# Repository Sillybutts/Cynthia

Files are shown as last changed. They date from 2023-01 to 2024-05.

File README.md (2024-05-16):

# Cynthia
Cynthia is a Talon mag fed bolt action blaster, customizable for any need. 

<details>
<summary>Changelog (click this text, it's a dropdown!)</summary>

- Changelog: 3-31-2023: Blaster release.
  
</details>

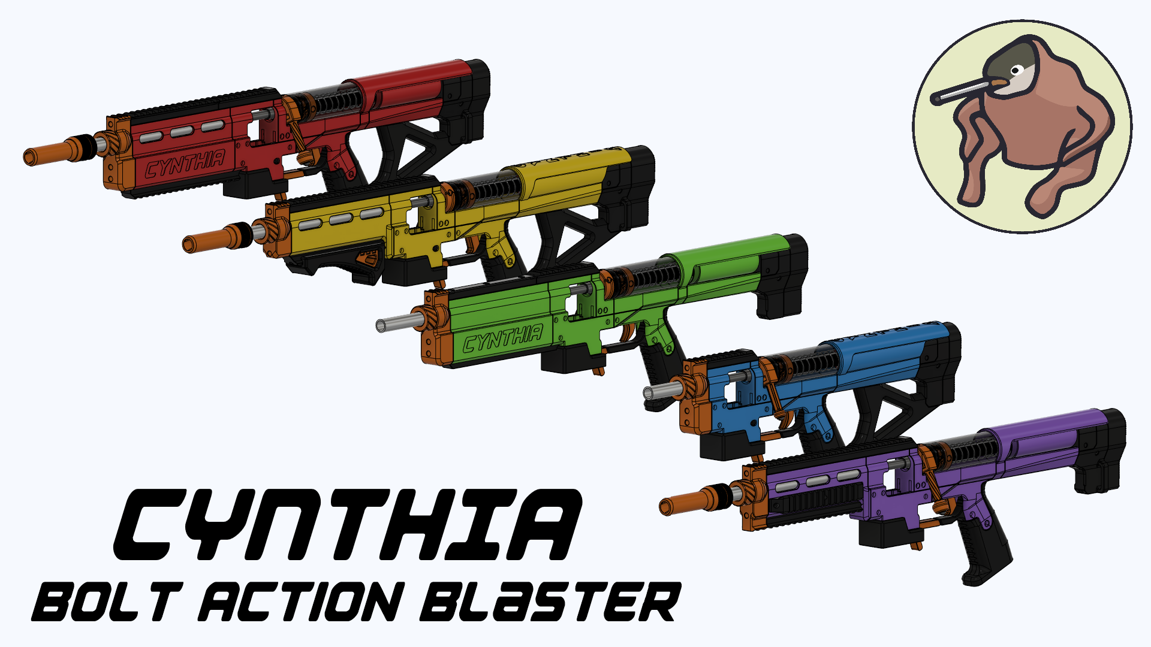
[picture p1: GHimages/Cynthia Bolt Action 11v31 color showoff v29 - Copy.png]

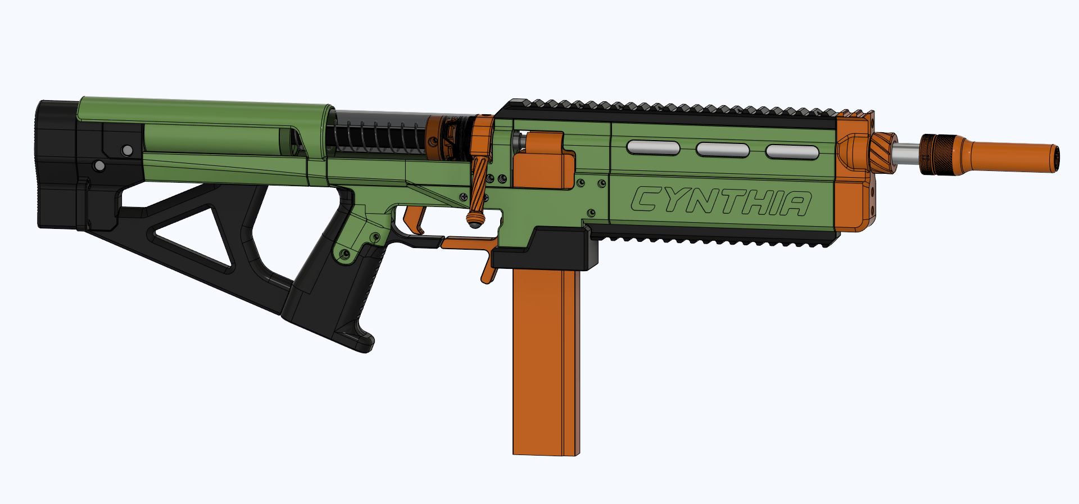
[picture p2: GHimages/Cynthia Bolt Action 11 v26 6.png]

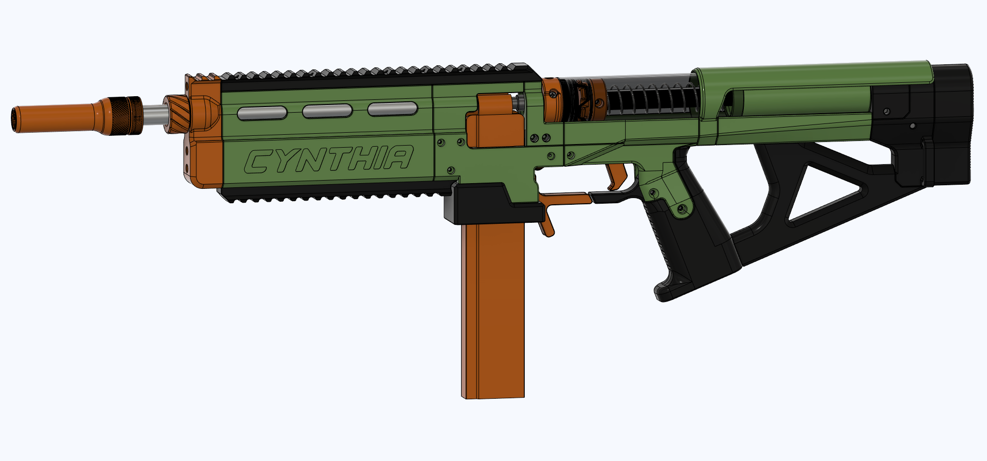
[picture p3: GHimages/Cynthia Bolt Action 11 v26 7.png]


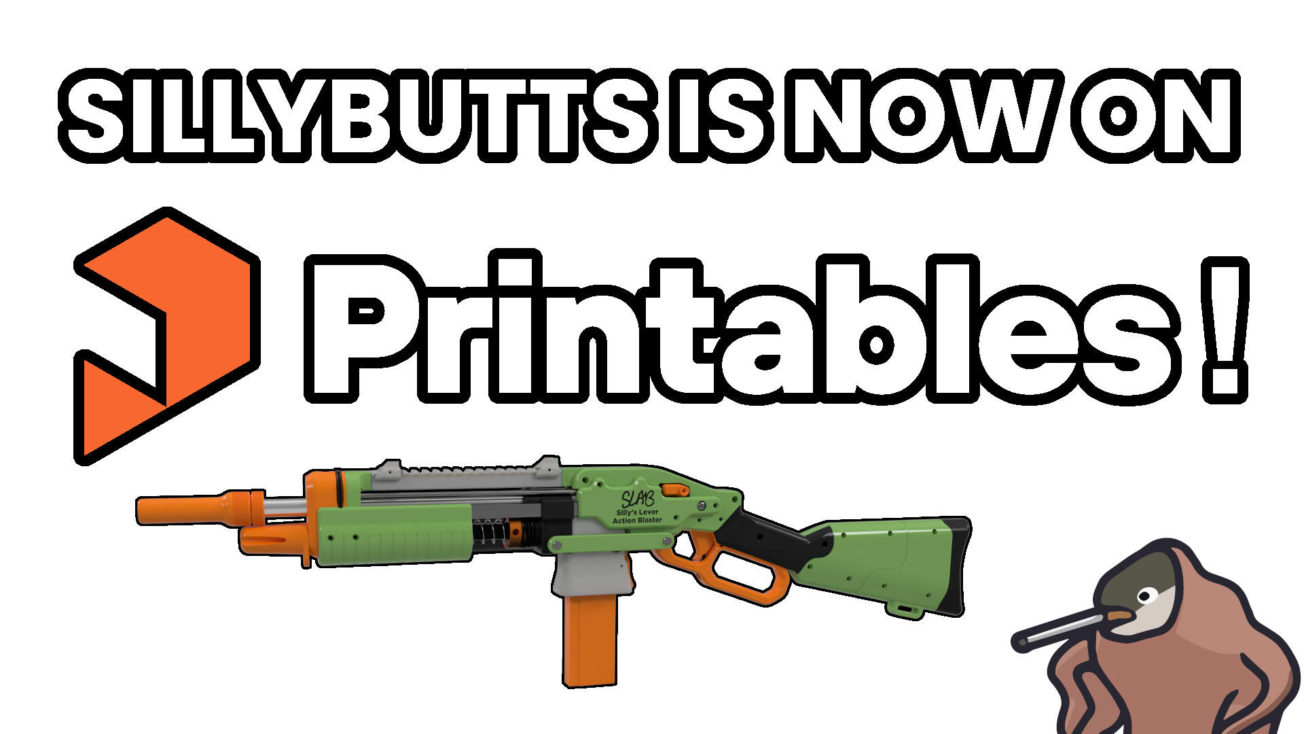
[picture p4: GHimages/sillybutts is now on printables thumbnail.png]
Printables Button


## I ALSO UPLOAD TO PRINTABLES https://www.printables.com/model/822838-cynthia-bolt-action-blaster-nerf-homemade

## Description

Cynthia is a bolt action blaster using the same basic layout as the Indra by CaptainSlug. Cynthia began with me figuring out how to fix all the issues with the Indra, but I pretty quickly realized it would be easier to design a whole new blaster from the ground up, rather than fix the Indra part by part.
Cynthia contains no original Indra parts. 

Firing Demo: https://youtube.com/clip/UgkxEHjsmXU370IFB8PHDxiK1v4qDb7vdCwZ

Blaster Overview: https://youtu.be/mIW0dAyOCv0

Customization Overview: https://www.youtube.com/watch?v=mZe6dWdQUs0

Assembly Video: https://youtu.be/j310YjRcwpU

## Reviews

Videos:

- Coop772: https://youtu.be/EAlBAFHLBZ4?si=m3mHurtMuX4kwWqg
- Captain Xavier: https://youtu.be/w24jp0K5Wfk?si=fWUyEQeJ973HoaAR
- Boomstick Mods: https://youtu.be/WF5V2YcIIjc?si=WsV3GZjRpdS0lTr-
- ZDL (China Spec): https://youtu.be/mkXsqYBOBpE?si=tJq3lU1MIqGpPgKb
- WalcomS7: https://www.youtube.com/watch?v=UhGpRX_KlXE
- BansheeIndian: https://www.youtube.com/watch?v=CzInCRDko88

## I don't charge for my files, please consider supporting me! 

**If you enjoy the stuff I make, please consider donating via Patreon or BuyMeACoffee. Filament and prototyping stuff costs a lot! By donating, I can make more cool stuff for everyone to enjoy. Thanks!**

<a href="https://www.patreon.com/sillybutts/">Patreon Button</a> 
https://www.patreon.com/sillybutts Monthly donations

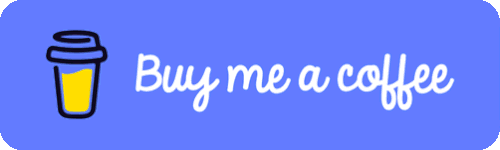
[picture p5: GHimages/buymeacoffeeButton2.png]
BuyMeACoffee Button
 
https://www.buymeacoffee.com/sillybutts One-time donations

## What does Cynthia fix vs the Indra?

The Indra by CaptainSlug is infamous for it's many issues. Thankfully, Cynthia fixes almost all the issues the Indra had:
- Fixed catch reliability by using the plunger system from the SLAB (modified to be longer)
- Improved plunger tube attachment strength (glue and more attachment area)
- Improved ramrod retention
- Made Cynthia slimmer
- Lengthened the stock to be Caliburn V4 length.
- Massively improved trigger feel
- Made the blaster lighter
- Less hardware cost
- Vastly improved front half rigidity
- A lot easier to assemble, disassemble, and swap springs.
- The thumbhole stock is easily removable, and is not required (on the Indra, the stock rod is required for blaster rigidity)
- Probably more stuff that I can't remember

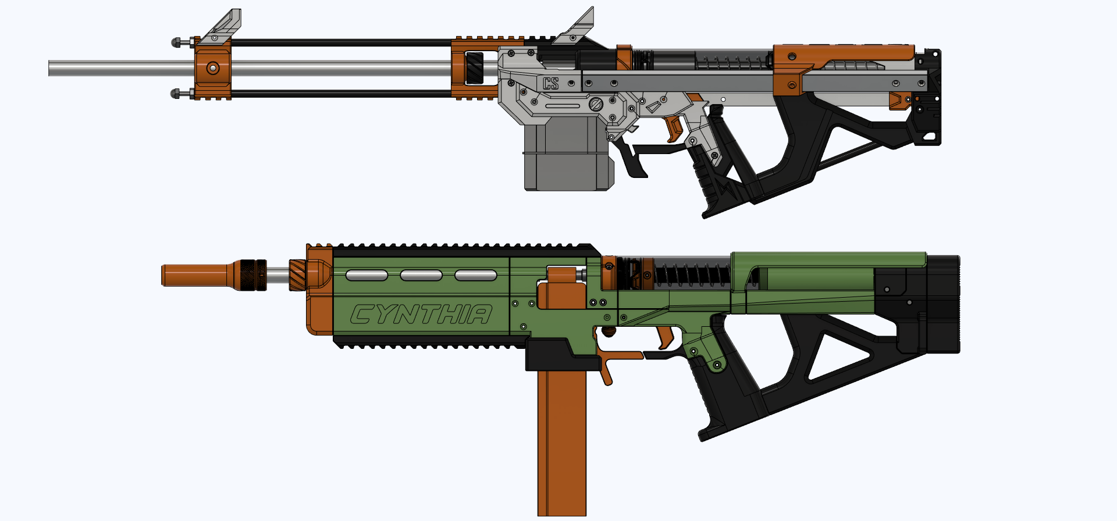
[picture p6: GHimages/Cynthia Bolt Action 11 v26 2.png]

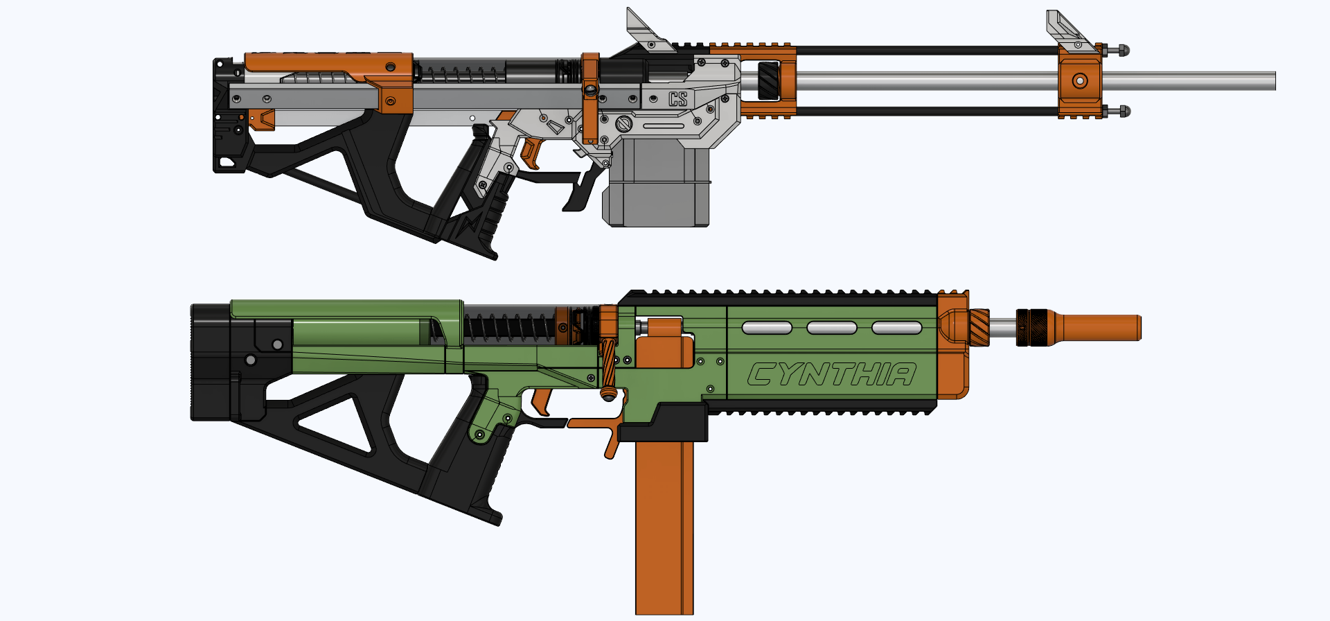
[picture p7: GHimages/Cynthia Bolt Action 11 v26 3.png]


## Optional Parts

There are many variant parts for Cynthia:
- Left and right handed parts
- Front Ends
- - Cynthia text or no Cynthia text
- - Ported and unported
- - Side rail or no side rail
- - Slim front end
- - Stubby short front end
- Two grip styles
- Several trigger styles
- Thumbhole stock or no thumbhole stock
- Fully enclosed plunger tube travel space, or open plunger tube space
- - Fully enclosed is good for people with beards, to protect yourself from hair-rippage during priming
- Tons of bolt handle options and lengths
- Locking bolt handle (for "realistic" bolt action coolness) or freely-moving bolt handle
- - Optional ball detent makes the bolt handle clicky as well, which feels really good.
- Optional muzzle with extra bottom picatinny (for bipod mounting)
- Optional picatinny rail replacements with no picatinny, for aesthetic sleekness
- Optional front grip
- Magwell panels with or without elastic holes, respectively for use with elastic or a spring on the mag release
- etc

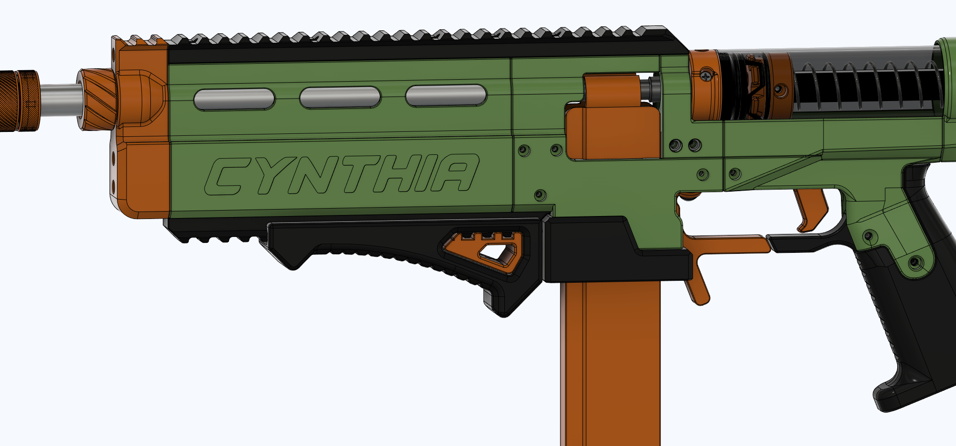
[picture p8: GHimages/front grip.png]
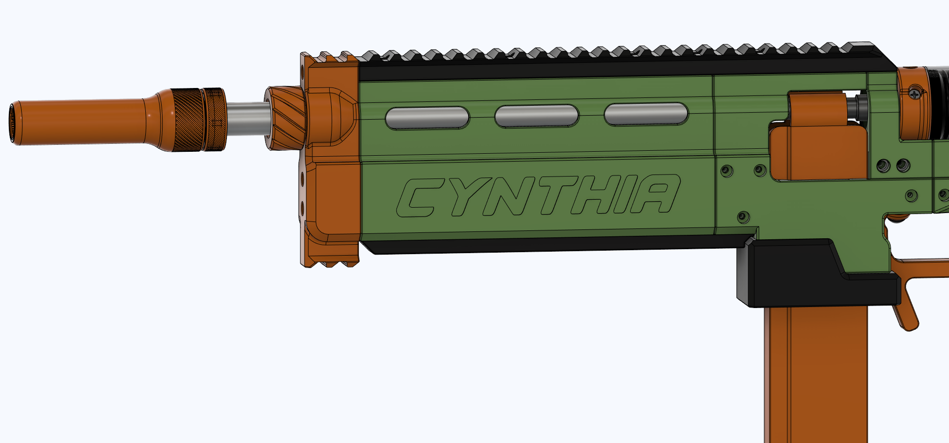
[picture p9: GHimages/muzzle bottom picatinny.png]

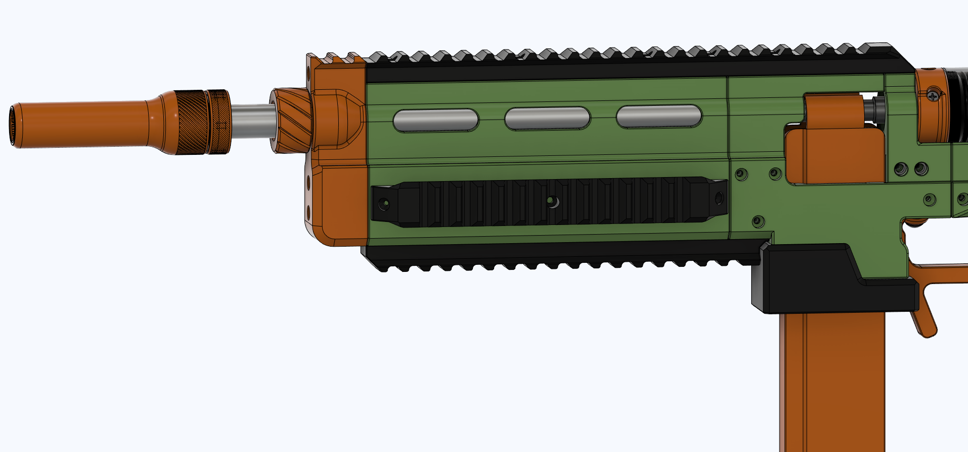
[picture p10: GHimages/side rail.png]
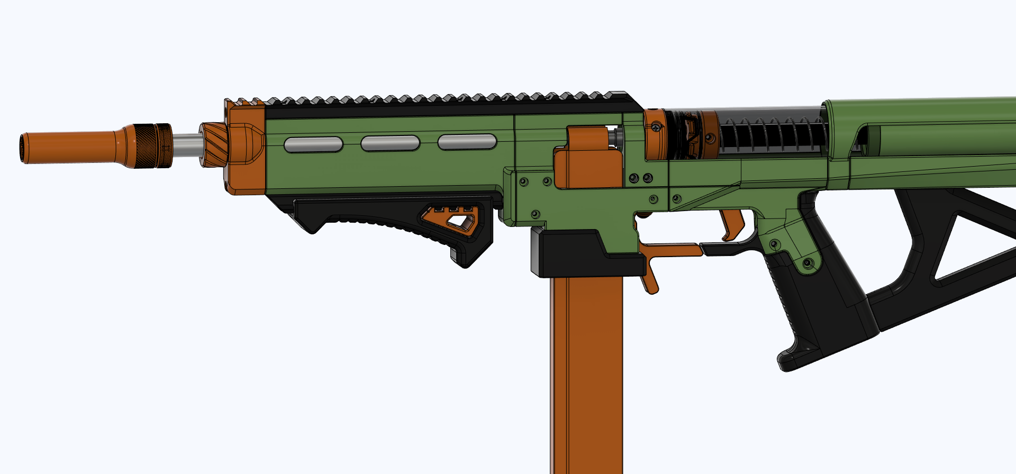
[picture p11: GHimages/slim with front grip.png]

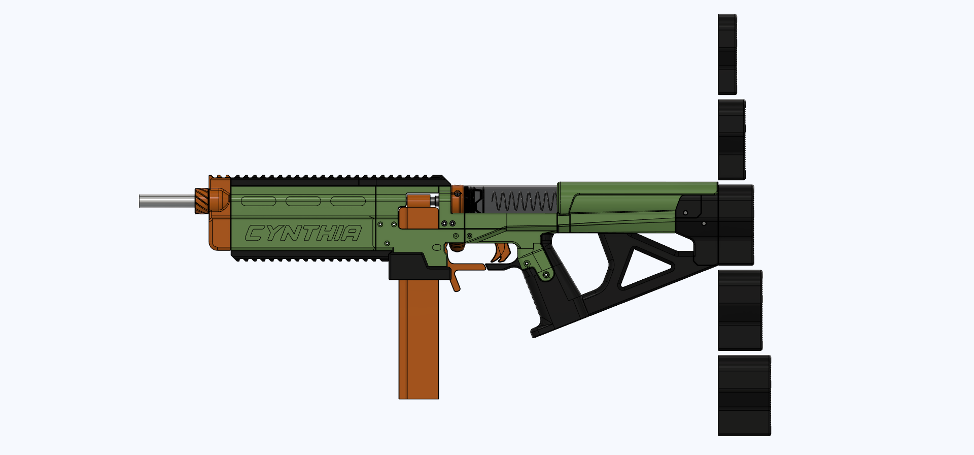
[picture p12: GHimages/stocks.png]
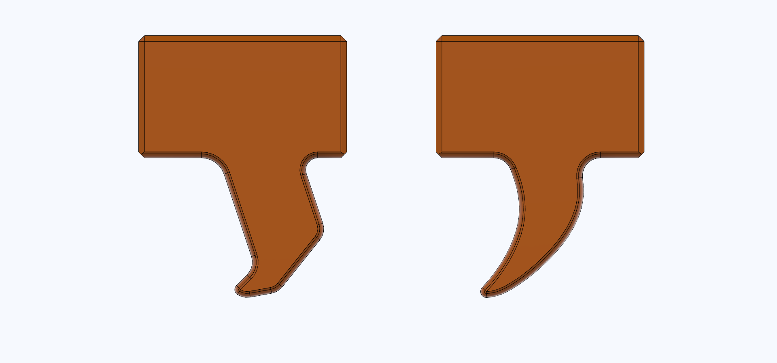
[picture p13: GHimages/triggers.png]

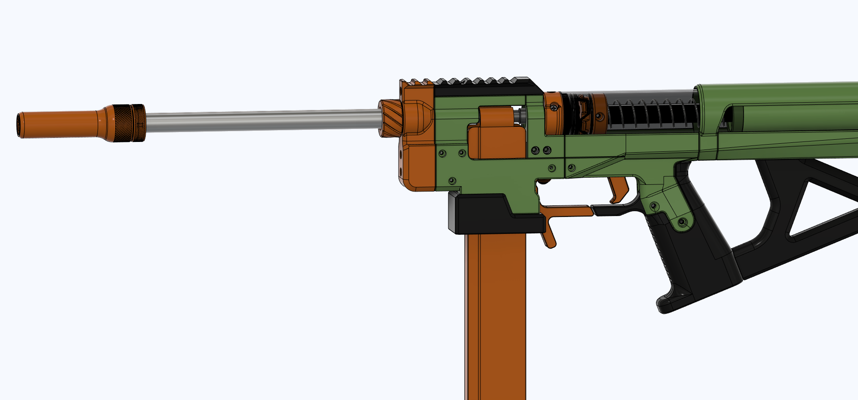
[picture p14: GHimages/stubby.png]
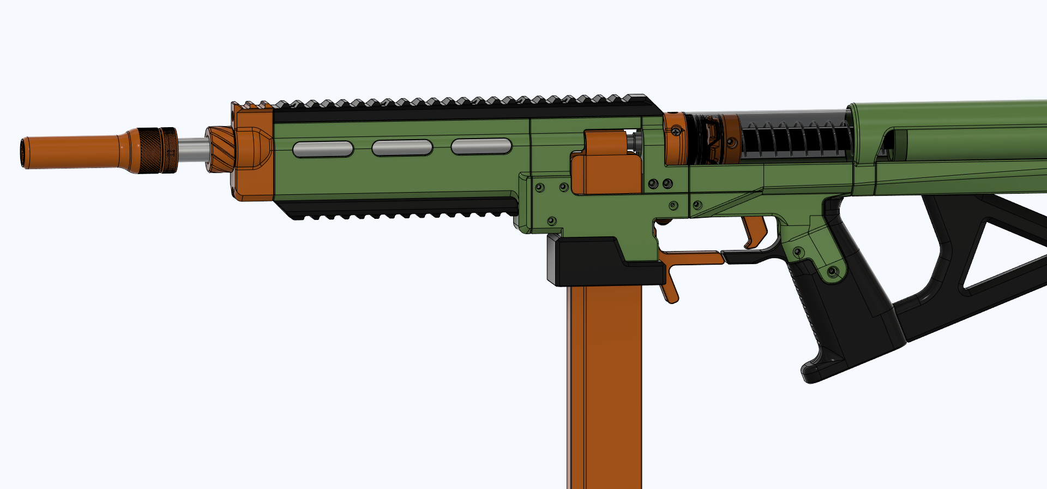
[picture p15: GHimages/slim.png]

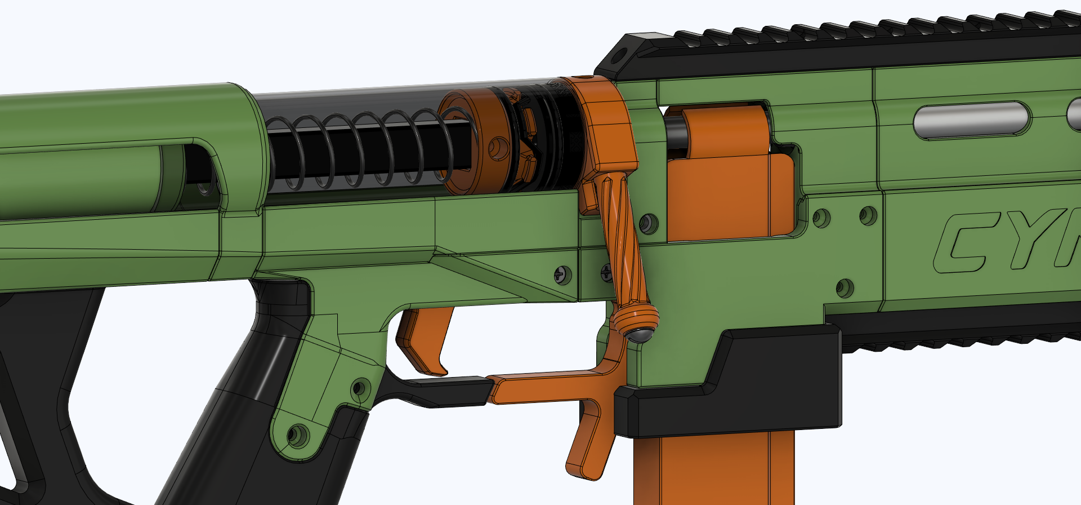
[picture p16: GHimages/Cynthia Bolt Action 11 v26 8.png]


Here are some good Picatinny sights if you want some:
- https://www.thingiverse.com/thing:2376150/files FrontPip and Pip in the Caliburn fileset are great iron sights.
- https://www.thingiverse.com/thing:1667830
- https://www.thingiverse.com/thing:2829229
- https://www.thingiverse.com/thing:5103083

### Performance:
As testing is done, I will update this part of the page with common spring/barrel combos for specific FPS numbers.

Keep in mind that SCARs usually reduce performance a bit.

Cynthia performance can be roughly approximated by using Talon Claw T4 performance estimates (in regards to barrel length and spring choice).

## Sellers
A full list of non-US sellers can be found here: https://www.stuffbysilly.com/wheretobuy

Hardware is available from these sellers:
- OutOfDarts: https://outofdarts.com/products/cynthia-hardware-kit
- SilverFoxIndustries: https://silverfoxindustries.shop/collections/new-products/products/cynthia-hardware-kit

Fully printed/assembled blasters are available from these sellers:
- OutOfDarts: https://outofdarts.com/products/cynthia-3d-parts-hardware-kit
- SilverFoxIndustries: WIP

## Print Info

Cynthia uses less than one 1kg PLA spool (if you were to print it all one color).

Infills:
- Black: 
- - PlungerRod, PlungerCap, 100% Gyroid, 5+ walls.
- - ThumbholeStock needs a brim.
- - Everything else, 20% Gyroid, 5 walls. 

- Orange: 
- - BoltBase, BoltHandle, FrontGripKeeper, Catch, CatchPusher, PlungerHead, 100% infill, 5 walls.
- - BoltHandle, FrontGripKeeper, CatchPusher need brims.
- - Everything else, 20% Gyroid, 5 walls. 

- Green: 
- - MagwellBack, Magwell_L, Magwell_R, Grip_L, Grip_R, 100% infill, 5 walls.
- - All the tall green parts benefit from a brim.
- - To be safe, I recommend you print each tall part one at a time.
- - Everything else, 20% Gyroid, 5 walls. 

Some parts have tight tolerances (mainly the dovetails in the catch area on the top cover print). Sanding and/or filing is recommended to make the dovetails go together smoothly. The top cover part can be broken if you try and force the dovetails together.

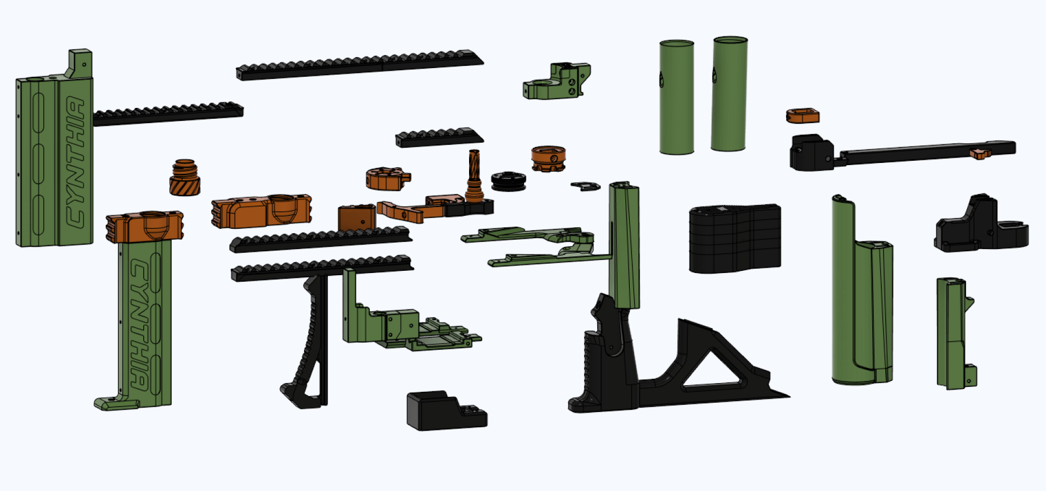
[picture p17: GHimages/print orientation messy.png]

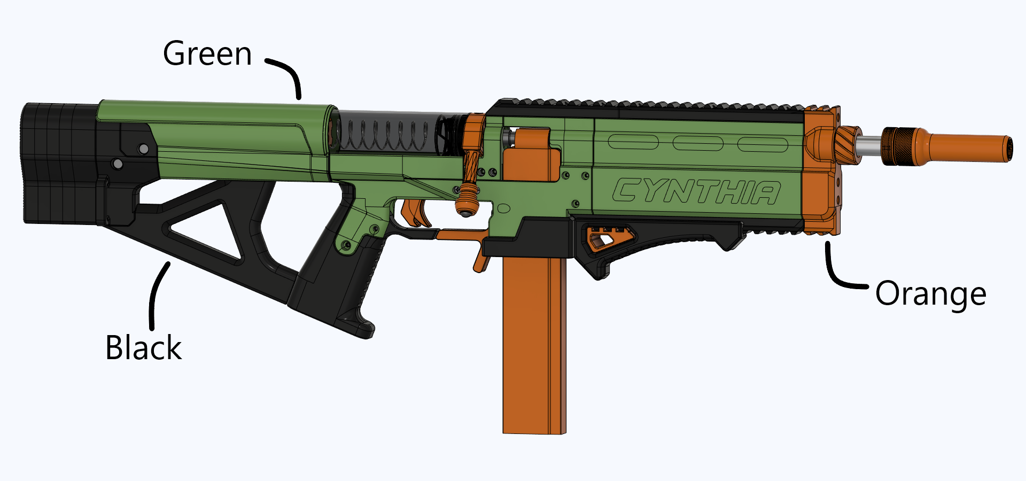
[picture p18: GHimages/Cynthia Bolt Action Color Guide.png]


## Hardware

Full hardware list: https://docs.google.com/spreadsheets/d/1t6-6BqBstn1Ad-zIxsB0FqWth3nB00lHC9SVksAbSmY/edit?usp=sharing

H4 bar spec for those interested: 

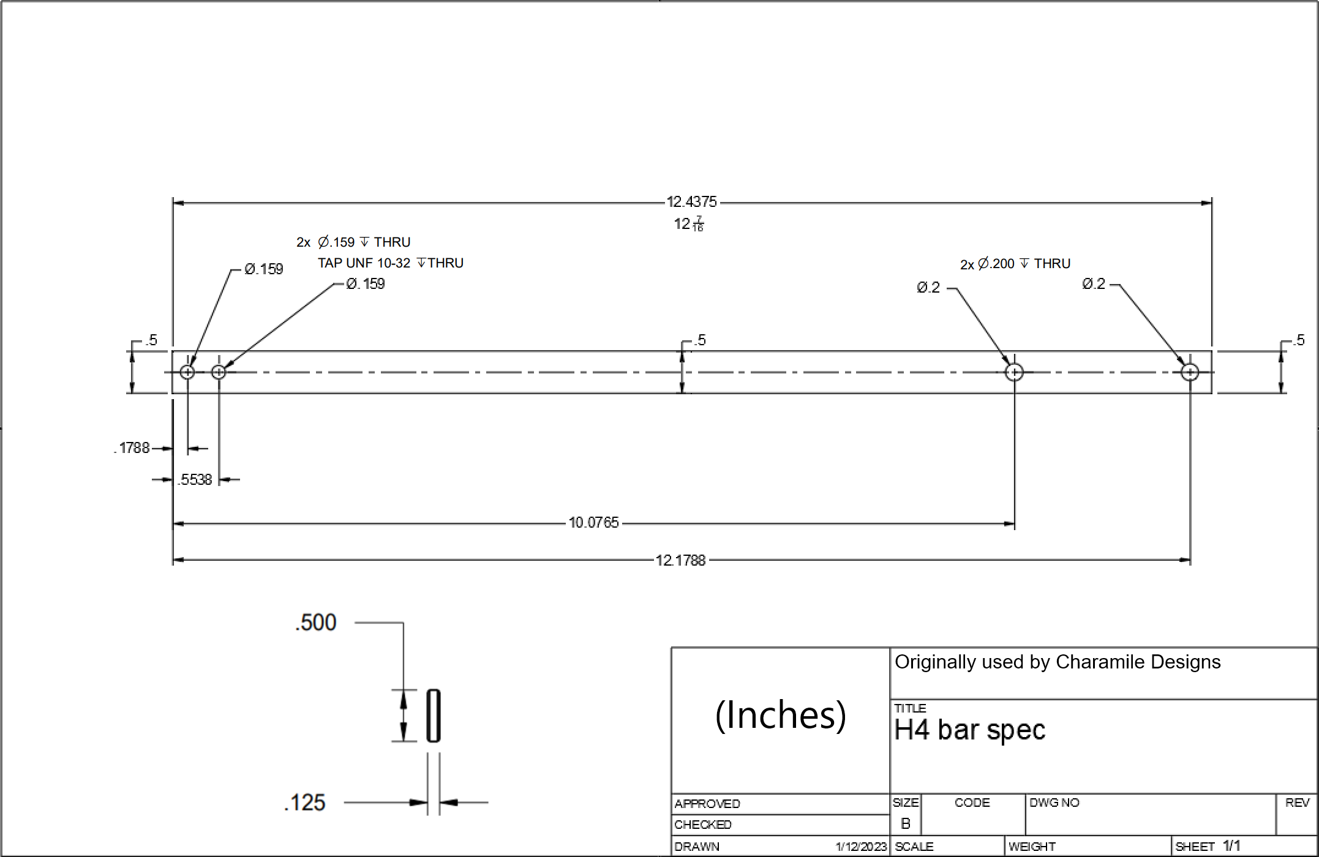
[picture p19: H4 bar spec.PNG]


H4 bars can be cut down from C4 bars using the bar cutting tool (included in Cynthia files).

## Assembly

Video: https://youtu.be/j310YjRcwpU

Catch assembly: https://youtu.be/D5Ouzac-vMs

Plunger Tube Gluing Guide: https://www.youtube.com/watch?v=0BNuwjhlNqI
(Super glue works, epoxy is best)

### Beta Tester Thanks
<details>
<summary>Thanks to my beta testers who contributed features and variant parts to Cynthia! Here's a list of who did what: (click this text)</summary>

- Chance made a new trigger for Cynthia, fixed some trigger wobble issues, and recommended adding a ball detent to the bolt handle.

Also, thanks to all my beta testers for their feedback while designing Cynthia. Couldn't have done it (this well) without you guys(and gals)!

- Chance
- WonderBoy
- BansheeIndian
- Greg from OutOfDarts
  
</details>

## Misc.

**If you build any of my designs, I'd love to see yours! Feel free to message me on Discord (Sillybutts#5905) or tag me on a post on Reddit (u/SillyTheGamer).**

**If you are having issues with any of my designs, let me know on Discord (Sillybutts#5905) or Reddit (u/SillyTheGamer).**

**If you wish to print and sell this item, please contact me for licensing. I can be reached on Discord (Sillybutts#5905) or Reddit (u/SillyTheGamer). iamsillybutts@gmail.com email too.**
**你好！ 我擁有這個設計。 想生產請聯繫我. 你好！ 我拥有这个设计。 如果你想生产，请联系我.**

<br />This work is licensed under a <a rel="license" href="http://creativecommons.org/licenses/by-nc-sa/4.0/">Creative Commons Attribution-NonCommercial-ShareAlike 4.0 International License</a>.

**Disclaimer: This is not a toy. This blaster is meant for hobbyists, not children. Blaster must be operated correctly to avoid injury. I am not responsible for any injuries from this blaster. Please use a bright/blaze orange muzzle and barrel cap on this blaster. Consult local laws before building this high powered blaster.**

## If you like what I do, please consider supporting me!

**I don't charge for my files, so any donations or merch purchases would be greatly appreciated!**

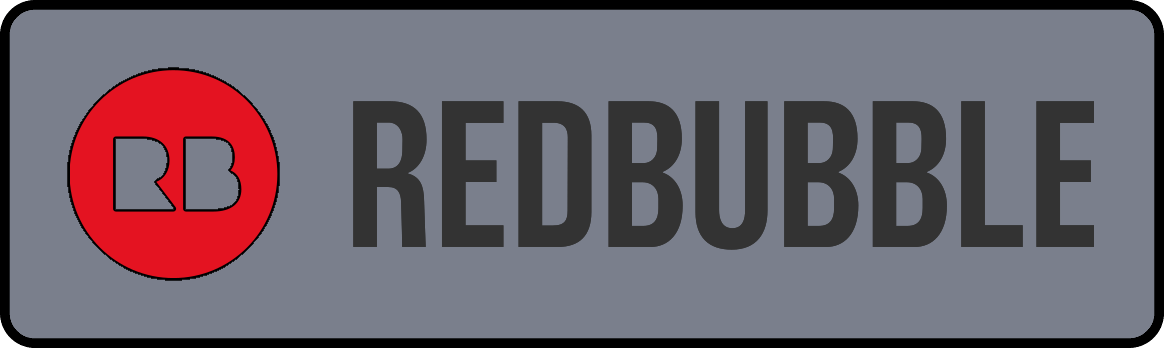
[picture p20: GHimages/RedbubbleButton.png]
RedBubble Button
 https://www.redbubble.com/people/Sillybutts/shop RedBubble full of fun Nerf-y sticker and merch designs!  

<a href="https://www.patreon.com/sillybutts/">Patreon Button</a> https://www.patreon.com/sillybutts Monthly donations

<a href="https://www.buymeacoffee.com/sillybutts/">BuyMeACoffee Button</a> https://www.buymeacoffee.com/sillybutts One-time donations

## Images

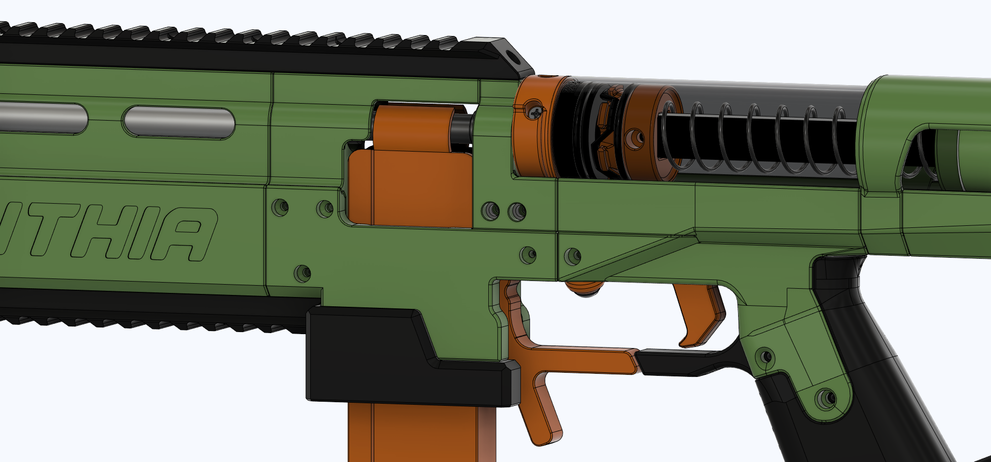
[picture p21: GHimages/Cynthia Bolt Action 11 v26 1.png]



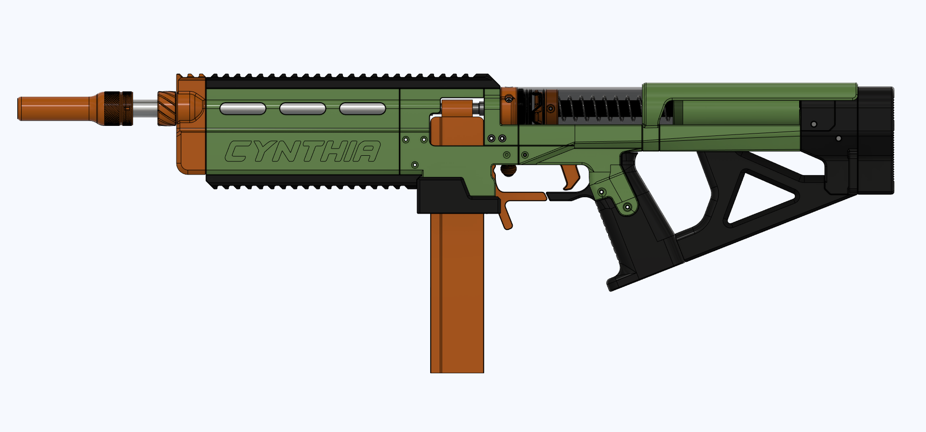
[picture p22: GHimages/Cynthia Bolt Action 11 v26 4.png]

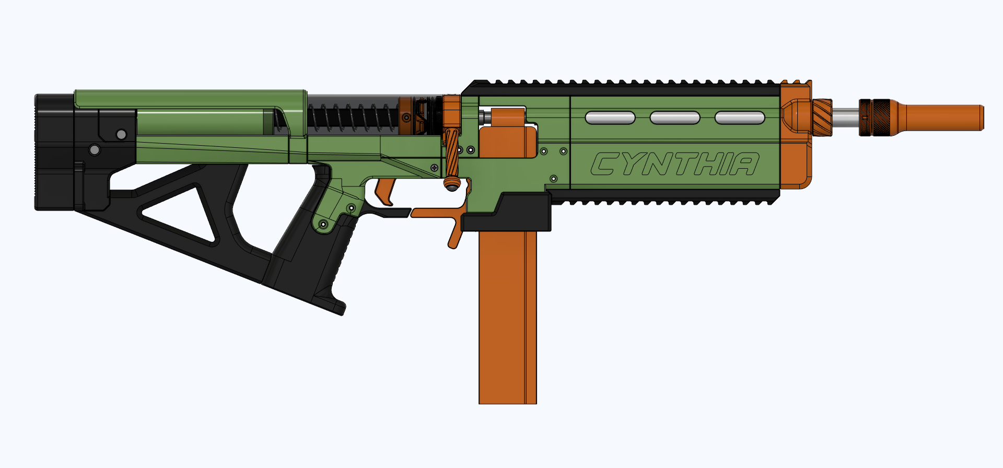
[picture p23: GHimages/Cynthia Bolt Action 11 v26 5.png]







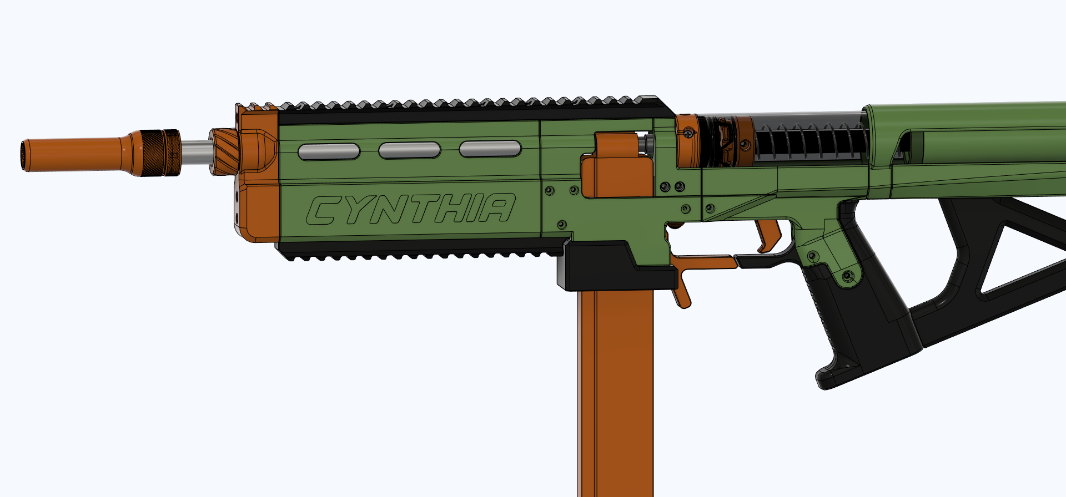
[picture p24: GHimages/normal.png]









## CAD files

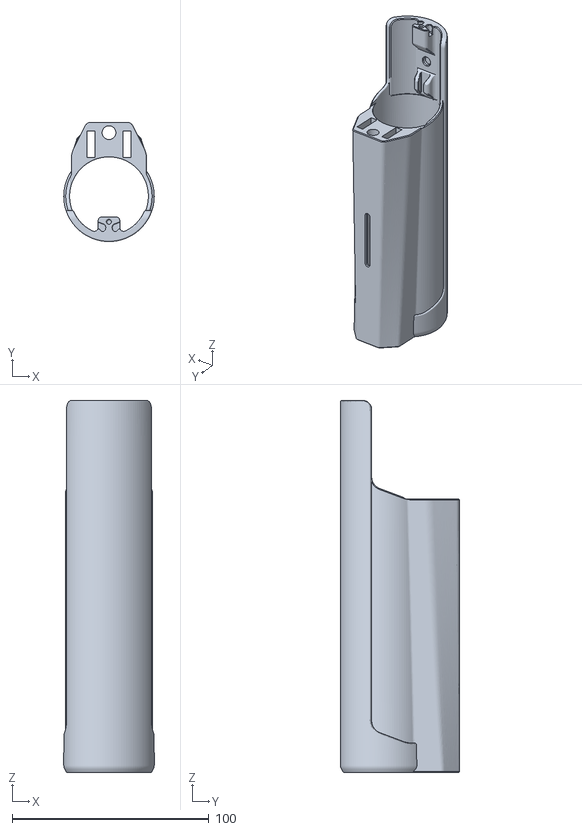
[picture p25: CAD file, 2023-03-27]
STLs/Green/PTcover_FULL_ReplacesBackBlock.stl
46.0 x 60.5 x 189.1

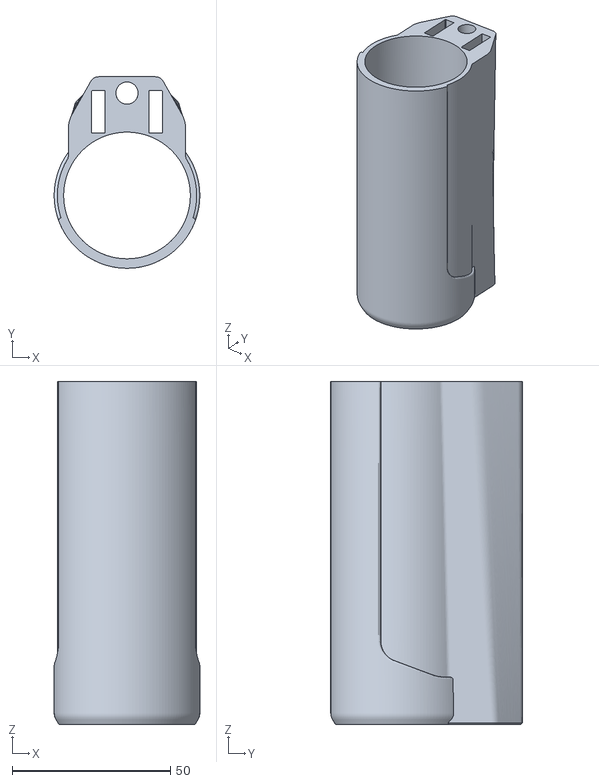
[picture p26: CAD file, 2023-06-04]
STLs/Alternate and Experimental/Split PTcover for smaller printers/SPLIT_PTcoverFULLFront.stl
46.0 x 60.5 x 108.3

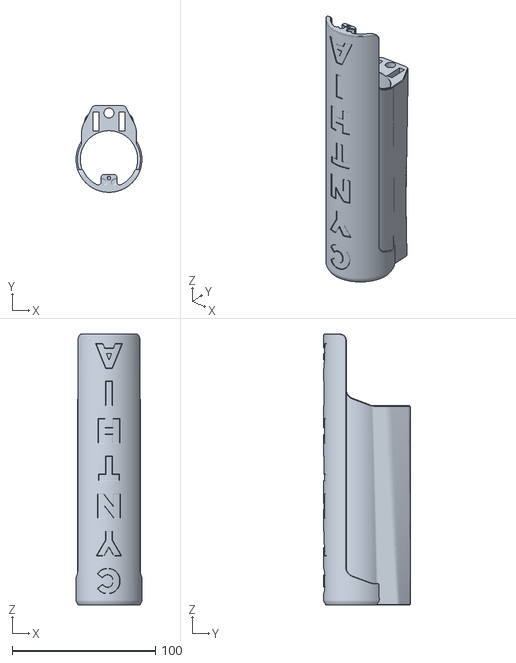
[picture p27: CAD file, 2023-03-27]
STLs/Green/PTcover_Logo_FULL_ReplacesBackBlock.stl
46.0 x 60.5 x 189.1

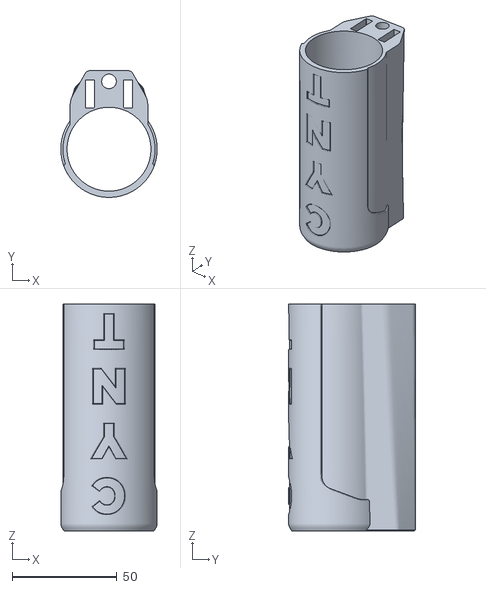
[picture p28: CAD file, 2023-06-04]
STLs/Alternate and Experimental/Split PTcover for smaller printers/SPLIT_PTcoverFULLFront_Logo.stl
46.0 x 60.5 x 108.3

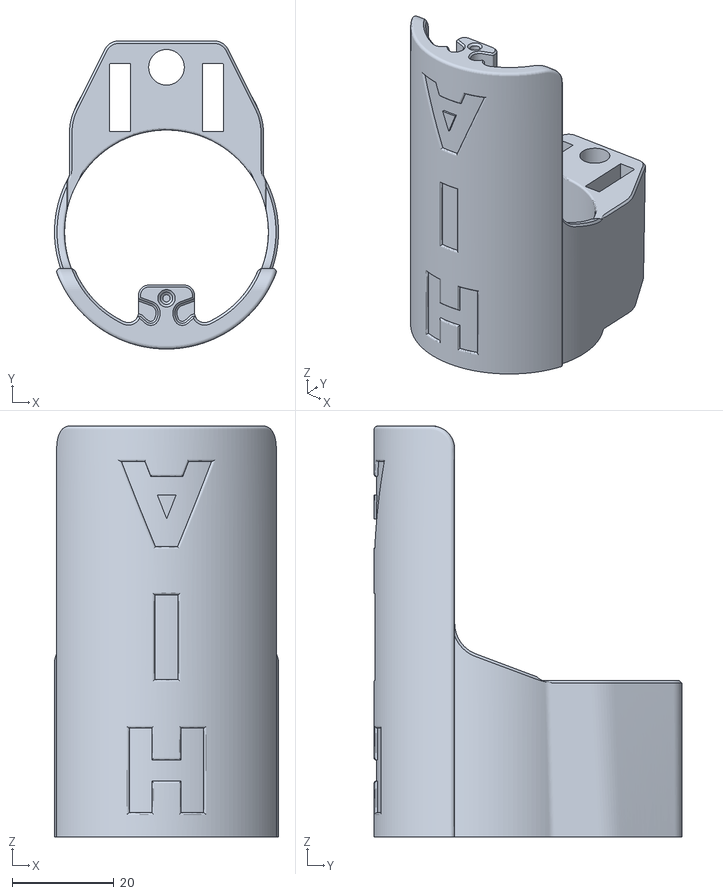
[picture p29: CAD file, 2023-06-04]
STLs/Alternate and Experimental/Split PTcover for smaller printers/SPLIT_PTcoverFULLBack_Logo.stl
44.0 x 60.5 x 80.7

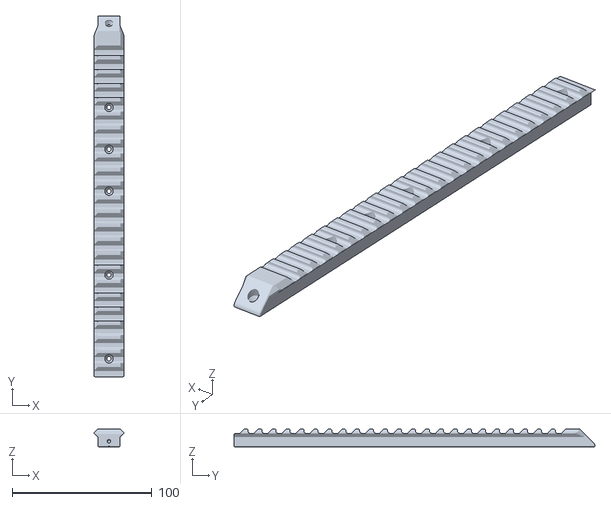
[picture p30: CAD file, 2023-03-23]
STLs/Black/TopRail_Full.stl
21.2 x 258.6 x 12.7

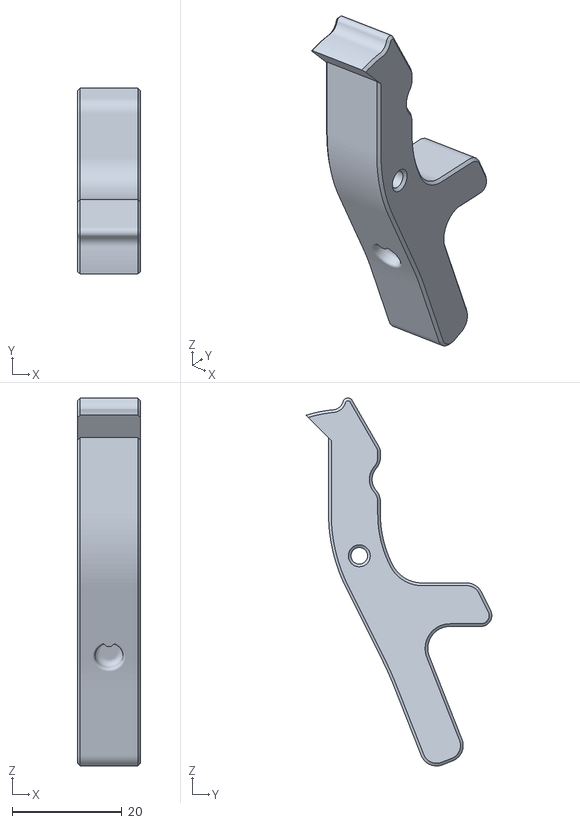
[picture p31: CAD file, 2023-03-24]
STLs/Alternate and Experimental/Alternate Mag Release and Trigger Guard/MagRelease_NOTRIGGERGUARDAREA.stl
11.5 x 33.8 x 67.0

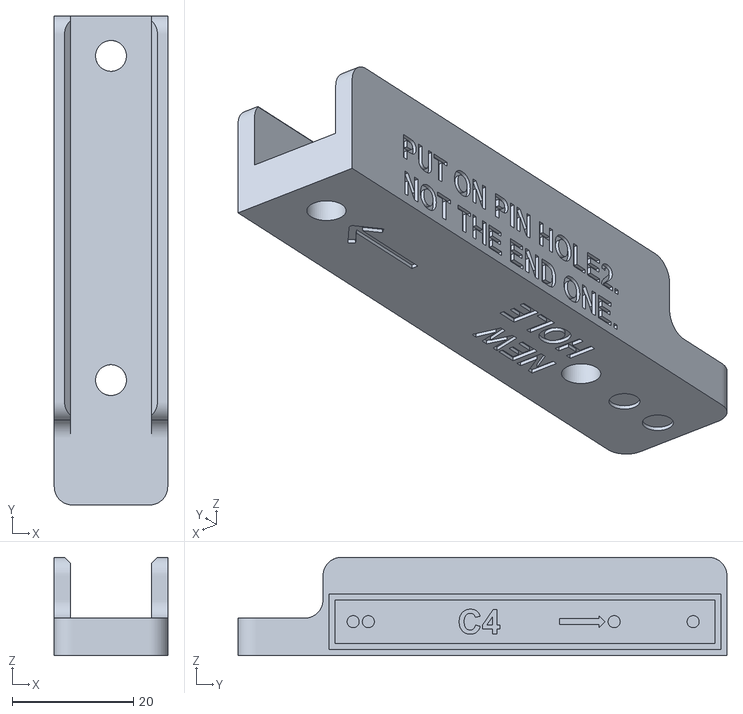
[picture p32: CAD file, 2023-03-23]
STLs/Alternate and Experimental/C4-TO-H4-CUTTING-AND-HOLE-JIG.stl
18.7 x 80.5 x 16.2

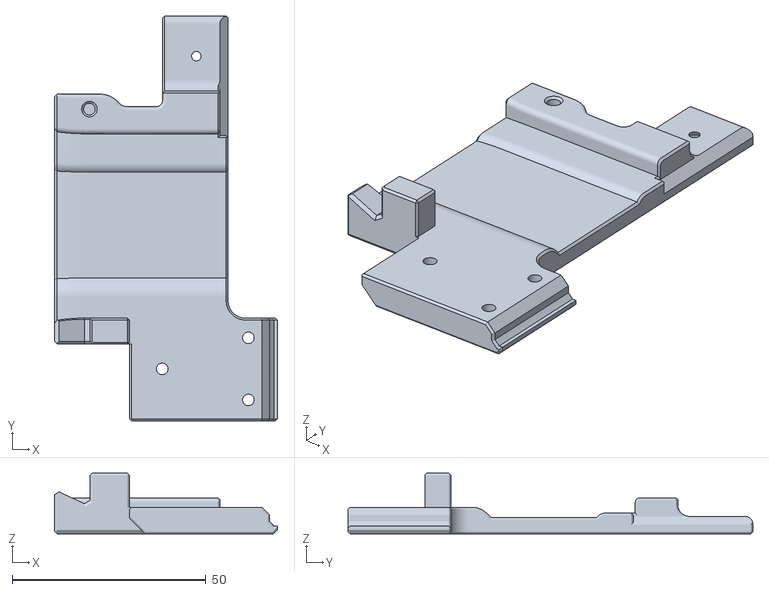
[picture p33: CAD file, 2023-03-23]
STLs/Alternate and Experimental/Magwell L-R with no elastic hole (small spring mag release ONLY)/Magwell_L_NOELASTICHOLE.stl
57.5 x 104.3 x 15.6

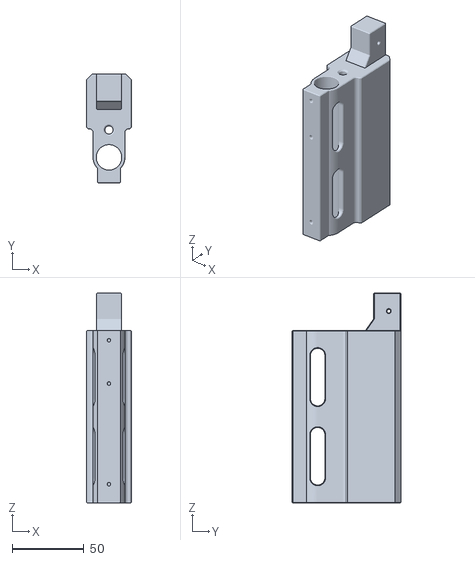
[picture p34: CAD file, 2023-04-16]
STLs/Alternate and Experimental/Shortened front (needs 5.5inch threaded rod)/SHORTENED_FrontBlock_Ported_Blank.stl
31.2 x 75.7 x 146.1

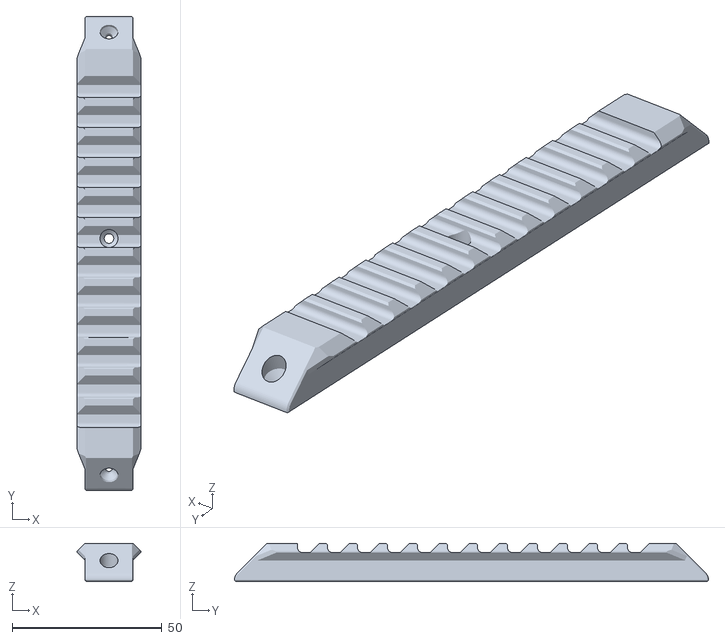
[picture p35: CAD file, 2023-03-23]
STLs/Alternate and Experimental/Slim front end/SLIM_SideRail_SIDERAILFRONTBLOCKONLY.stl
21.2 x 158.1 x 12.7

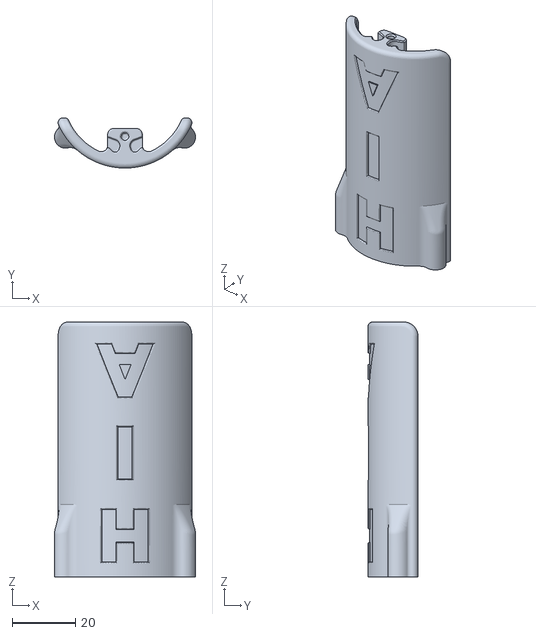
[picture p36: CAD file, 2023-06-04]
STLs/Alternate and Experimental/Split PTcover for smaller printers/SPLIT_PTcoverBack_Logo_NEEDSABRIM.stl
44.7 x 15.9 x 80.7

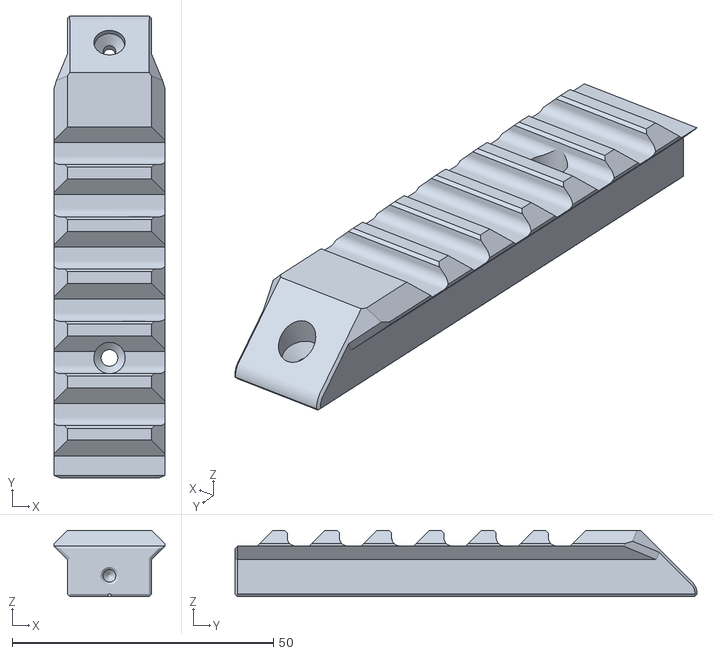
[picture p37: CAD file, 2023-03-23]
STLs/Alternate and Experimental/Stubby front end/TopRail_Stubby.stl
21.2 x 88.5 x 12.7

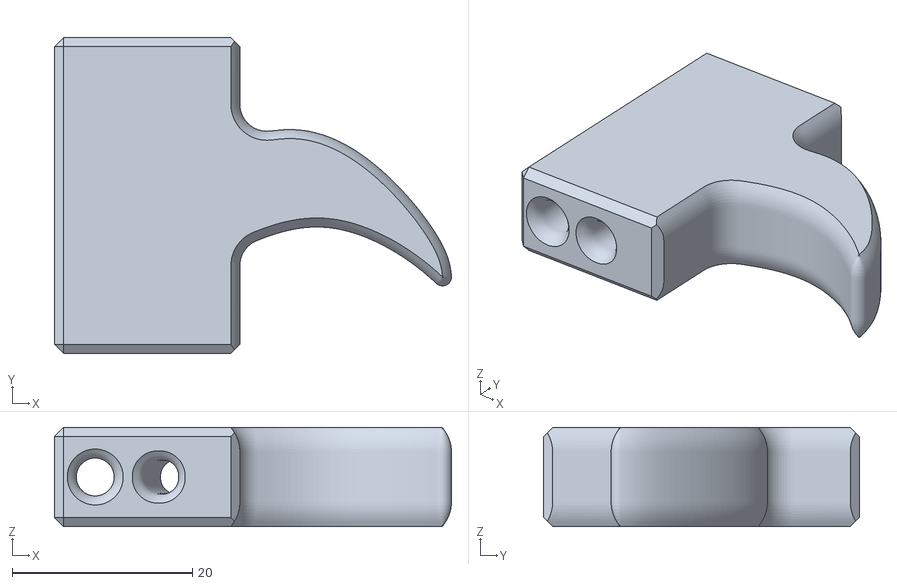
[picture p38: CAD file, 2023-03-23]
STLs/Alternate and Experimental/Triggers for optional 10-32 Heat Set Insert/HEATSET_Trigger_Thicker_ChanceStyle.stl
44.0 x 35.0 x 11.0

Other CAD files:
STLs/Alternate and Experimental/Split PTcover for smaller printers/SPLIT_PTcoverFULLBack.stl
STLs/Black/PlungerRod_Thinner (for tighter springs like k26).stl
STLs/Green/Left Handed/MagwellBack_LH_Locked.stl
STLs/Green/Right Handed/MagwellBack_RH_Unlocked.stl
STLs/Alternate and Experimental/Alternate Mag Release and Trigger Guard/TriggerGuard_LONGERFORALTERNATEMAGRELEASE.stl
STLs/Alternate and Experimental/Magwell L-R with no elastic hole (small spring mag release ONLY)/Magwell_R_NOELASTICHOLE.stl
STLs/Alternate and Experimental/MegaXL Spigot SCAR/BarrelCap.stl
STLs/Alternate and Experimental/MegaXL Spigot SCAR/Merlynn MXLspigotSCAR.stl
STLs/Alternate and Experimental/MegaXL Spigot SCAR/Nut_Hex MXLspigotSCAR.stl
STLs/Alternate and Experimental/MegaXL Spigot SCAR/Nut_Knurled MXLspigotSCAR.stl
STLs/Alternate and Experimental/MegaXL Spigot SCAR/Nut_Knurled_Short MXLspigotSCAR.stl
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

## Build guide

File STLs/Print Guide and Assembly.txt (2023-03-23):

-------------------------------------------------------------------------------------------------------------------------------------------------------------------------------------
PRINT GUIDE: Cynthia Bolt Action Blaster
-------------------------------------------------------------------------------------------------------------------------------------------------------------------------------------
Printing Info
All STLs were exported in print orientation. F3D & STEP source files are also provided.

This blaster is designed for PLA parts. Printing in other filaments (like PETG) should be fine, but might lead to broken parts.

-------------------------------------------------------------------------------------------------------------------------------------------------------------------------------------
Infills:
- Black: 
- - PlungerRod, PlungerCap, 100% Gyroid, 5+ walls.
- - ThumbholeStock needs a brim.
- - Everything else, 20% Gyroid, 5 walls. 

- Orange: 
- - BoltBase, BoltHandle, FrontGripKeeper, Catch, CatchPusher, PlungerHead, 100% infill, 5 walls.
- - BoltHandle, FrontGripKeeper, CatchPusher need brims.
- - Everything else, 20% Gyroid, 5 walls. 

- Green: 
- - MagwellBack, Magwell_L, Magwell_R, Grip_L, Grip_R, 100% infill, 5 walls.
- - All the tall green parts benefit from a brim.
- - To be safe, I recommend you print each tall part one at a time.
- - Everything else, 20% Gyroid, 5 walls. 

-------------------------------------------------------------------------------------------------------------------------------------------------------------------------------------
MegaXL Spigot SCAR Print Settings

Included in the SLAB fileset is a SCAR that allows you to fire MegaXL darts, and have a fully air-sealed SCAR.

Print all of the SCAR at 5 walls 20% infill. No supports are necessary, but a brim might be needed to print smoothly.

Make sure the Z-Seam is straight down one side of the SCAR. Otherwise, it might not launch MegaXL as nicely, and it looks bad with misaligned Z-Seams.

-------------------------------------------------------------------------------------------------------------------------------------------------------------------------------------
ASSEMBLY: WIP VIDEO
-------------------------------------------------------------------------------------------------------------------------------------------------------------------------------------

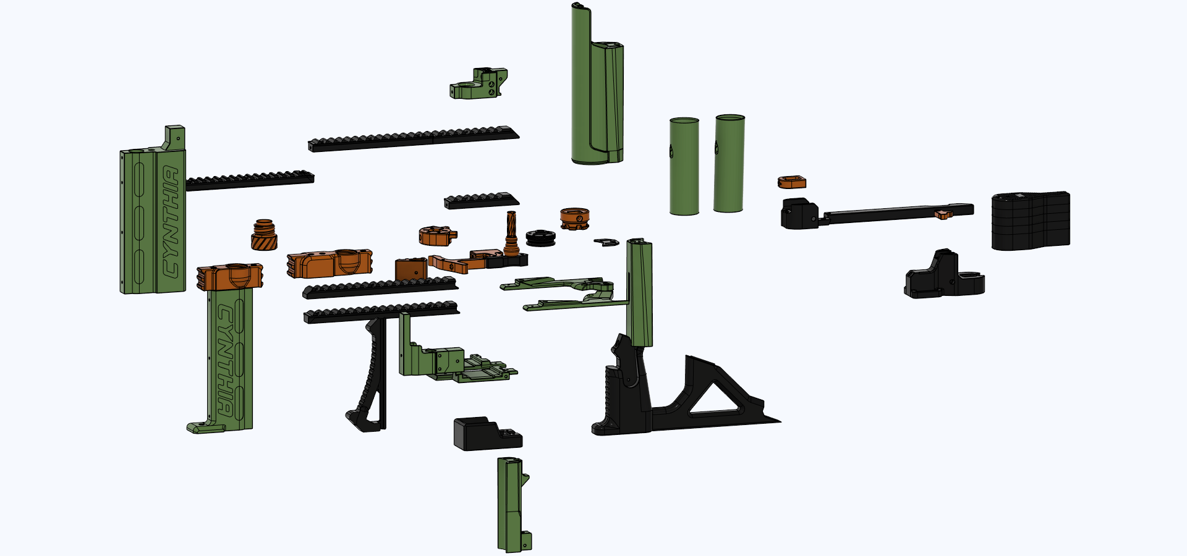
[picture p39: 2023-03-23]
STLs/Cynthia Bolt Action 11 print orientation v4.png

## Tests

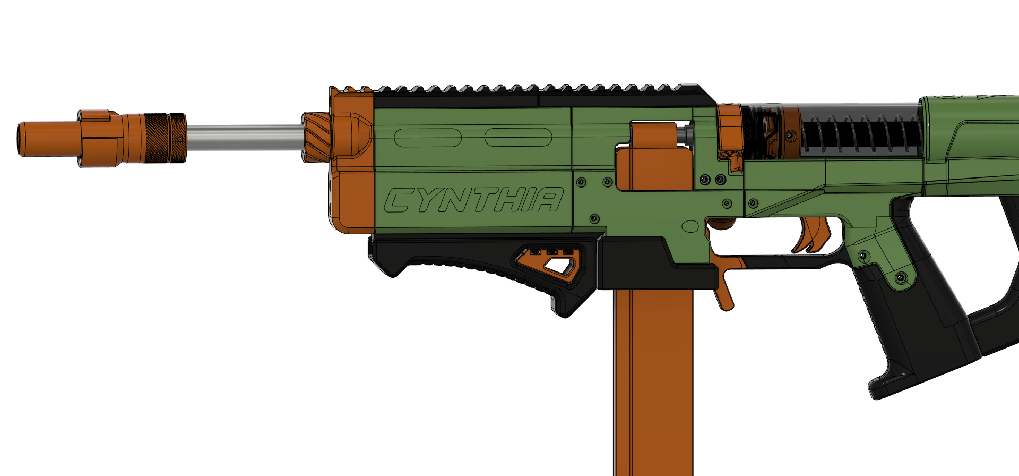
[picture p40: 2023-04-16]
STLs/Alternate and Experimental/Shortened front (needs 5.5inch threaded rod)/Cynthia Bolt Action 11 v43 1.png
